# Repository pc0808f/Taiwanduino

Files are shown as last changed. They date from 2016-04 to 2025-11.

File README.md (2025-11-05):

# Taiwanduino

Hi, this is the official project site of Taiwanduino
* For our hardware design, please go to [/hardware][hw]
* Our software stuff (bootloader, driver, Arduino sketch...etc) is at [/software][sw]
* Our holder model has been released, it's located at [/holder][hd]

For installation or assembly instructions, see our [Wiki page][wiki]
Like our facebook [fan page][fb] for more info, online shop or donations!

[Changelog]
2025/11/05 (pc0808f fork) - v1.0.3
Fixed: Support for USBasp/USBtiny programmer with custom USB ID 1209:5457
Changed: Reverted to v1.0.2 style using arduino:usbtiny as upload tool
Programmer: "Taiwanduino" option available (uses local avrdude.conf for custom USB IDs)
Note: Direct upload uses Arduino core tools; "Upload Using Programmer" supports VID:1209 PID:5457

2025/10/29 (pc0808f fork) - v1.0.2
Fixed: Examples now visible in Arduino IDE after Board Manager installation
Added library.properties file for bundled library
Updated board package structure to follow Arduino specification

2025/10/28 (pc0808f fork) - v1.0.1
Updated board manager URL to pc0808f fork version
Re-committed zip file for GitHub Pages sync

2017/9/24
Add a 7 tones simple instrument example sketch

2016/11/11
Support for the latest CapacitiveSensor library from the Library Manager

2016/10/31
Holder v1.0 released

2016/10/27
Add pcm audio converter tools/pcm_converter
Cleanup example sketches

***

*Read this in other languages: [English](README.md), [繁體中文](README.zh-TW.md).*

TaiwanDuino

   [wiki]: <https://github.com/pc0808f/Taiwanduino/wiki>
   [hw]: <https://github.com/pc0808f/Taiwanduino/tree/master/hardware>
   [sw]: <https://github.com/pc0808f/Taiwanduino/tree/master/software>
   [hd]: <https://github.com/pc0808f/Taiwanduino/tree/master/holder>
   [fb]: <https://www.facebook.com/Taiwanduino>

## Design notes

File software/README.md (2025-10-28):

# Software

**Board Manager Installation** (Recommended)
   If you have the latest Arduino IDE, you can use *Board Manager* and *Library Manager* to download and install automatically

   Note: The board configuration files are located in `/hardware/Taiwanduino/avr/` directory

 - Board Configs
	 - [File] → [Preferences] → [Additional Board Manager URLs] and insert the URL below:
	   https://pc0808f.github.io/Taiwanduino/taiwanduino_pc0808f_index.json
	 - [Tools] → [Board: ""] → [Board Manager] and search for "Taiwanduino"
	 - Click the [Install] button

 - External libraries
	 - [Sketch] → [Include library] → [Manage Libraries] and search for "CapacitiveSensor"
	 - Click the [Install] button
	 - The library could be found in [PaulStoffregen/CapacitiveSensor](https://github.com/PaulStoffregen/CapacitiveSensor) if you want to import it manually

**Driver** contains drivers for Windows systems (it's a plug and play device for UNIX based systems like OS X or Linux)

**bootloader** contains the source code of the pre-programmed bootloader in TaiwanDuino

**example** is the folder of example sketches

**tools** includes EEPROM programmer and audio converters

***

*Read this in other languages: [English](README.md), [繁體中文](README.zh-TW.md).*

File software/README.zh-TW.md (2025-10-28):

# Software

**板子管理員安裝**（建議使用）
   可以透過下載最新版的 Arduino IDE 並使用內建的*板子管理員*及*管理程式庫*功能來自動安裝

   註：板子配置檔案位於 `/hardware/Taiwanduino/avr/` 目錄

 - 板子編譯資訊
	 - 請在 [檔案] → [偏好設定] → [額外的板子管理員網址]中輸入以下網址：
	   https://pc0808f.github.io/Taiwanduino/taiwanduino_pc0808f_index.json
	 - 進入 [工具] → [板子] → [板子管理員]中搜尋 Taiwanduino
	 - 按下 [安裝] 按鈕

 - 所使用的外部函式庫
	 - [草稿碼] → [匯入程式庫] → [管理程式庫]中搜尋 CapacitiveSensor
	 - 按下 [安裝] 按鈕
	 - 手動匯入外部程式庫請至 [PaulStoffregen/CapacitiveSensor](https://github.com/PaulStoffregen/CapacitiveSensor) 下載

**Driver** 資料夾中包含 Windows 作業系統所需驅動程式（OS X 和 Linux 為隨插即用）

**bootloader** 包含 TaiwanDuino 中所預燒的 bootloader 原始碼

**example** 為範例草稿碼的資料夾

**tools** 內有燒錄、製作音訊時所需的轉換工具

***

*其他語言版本: [English](README.md), [繁體中文](README.zh-TW.md).*

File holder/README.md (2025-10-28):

# Holder

We've finally finished the designing and testing process of our holder model, it contains screw pillars and a housing for your speaker.

 - Screw pillars are designed for any M2 screws (same size of the touchpad hole) within 7mm length.
 - The speaker housing includes 7 air holes and an internal support material to increase resonance, the bottom with air holes also acts like a mask to protect the diaphragm of speaker.

[holder_model-Main_Holder_STL.stl][stl] is the latest STL model you can print directly
[holder_model.blend][blend] is our project file made with Blender

***

*Read this in other languages: [English](README.md), [繁體中文](README.zh-TW.md).*

   [stl]: <holder_model-Main_Holder_STL.stl>
   [blend]: <holder_model.blend>

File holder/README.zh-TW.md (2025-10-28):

# 外殼

經過一連串的設計和測試，我們最終決定了包含螺絲腳柱和喇叭固定槽的外殼

 - 螺絲角柱的部分使用的是和觸控 PAD 相同孔徑的 M2 螺絲，小於 7mm 的 M2 螺絲都是可以被鎖上的
 - 喇叭固定槽包含 7 個發聲孔和一個 0.7mm 的增高墊，讓喇叭震模不會直接和外殼底面接觸，並且可以藉由發聲孔傳出聲波

進入 [holder_model-Main_Holder_STL.stl][stl] 下載可以直接進行列印的 STL 模型檔
進入 [holder_model.blend][blend] 下載本模型的 Blender 專案檔

***

*其他語言版本: [English](README.md), [繁體中文](README.zh-TW.md).*

   [stl]: <holder_model-Main_Holder_STL.stl>
   [blend]: <holder_model.blend>

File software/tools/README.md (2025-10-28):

# pcm_converter
Drag and drop multiple audio files and convert it to 8bit PCM audio

First, make a shortcut of this converter pcm_converter_en.bat and move it to where your audio file locate.
Drag and drop multiple audio/video file on the shortcut at once.
After the conversion, you will be able to find 8bit PCM(.wav) files in the /export folder.
Default sample rate and export location can be changed manually in the batch program.

Notice: An auto libav downloader will be triggered at the first time you start.

# wav2txt
Extracts converted the PCM(.WAV) audio file to an array of samples, paste it in sketch and play

Drag and drop the .wav file on writeWav.exe.
It will extract a text file(.txt) which has the same name as the original.
Paste the content (array+size variable) to your Arduino sketch and upload.

Notice: only 8khz/8bit or 16bit in a audio format of PCM will be available.

# wav2uart
Programs the converted the PCM(.WAV) audio file to external EEPROM, it must be connected through a Serial converter (i.e. FTDI)

First, upload the [example/uploadToFlash](../example/uploadToFlash) to your Taiwanduino.
Start wav2uart.exe
Copy and paste your file location in.
Choose the COM port device your Taiwanduino is connected.
Enter the data offset in EEPROM (where you start to program)

Notice: only 8khz/8bit or 16bit in a audio format of PCM will be available.

***

*Read this in other languages: [English](README.md), [繁體中文](README.zh-TW.md).*

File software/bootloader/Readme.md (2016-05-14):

# Arduino_Taiwan Bootloader

Modify from Adafruit ProTrinket
Change USB pin to 2/3
also change USB PID/VID

#using Avrdude to upload  

.\avrdude.exe  -c usbasp -p m328p -v -e  -U flash:w:main.hex -U lfuse:w:0xFF:m -U hfuse:w:0xD0:m -U efuse:w:0x06:m

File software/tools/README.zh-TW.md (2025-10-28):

# pcm_converter
把有帶音訊資料的任意影音檔案，透過拖曳的方式快速轉檔

直接將主程式 pcm_converter_tw.bat 檔建立一個捷徑並傳送到音效檔的資料夾
把所要轉換的一個或多個音效檔案拖曳到剛剛建立的捷徑上面即可完成轉檔
所輸出的檔案將會是 8 位元的 PCM 編碼 WAV 檔
預設取樣率和輸出資料夾可以至程式中進行手動更改

注意事項：第一次使用會先下載一份 libav 的轉檔器

# wav2txt
把 WAV 轉成程式碼，然後就可以貼上 example 播放

使用方式是把聲音檔案拖到 .exe 檔案裡面
之後會在同個地點多出一個 txt 檔案，把這檔案內容複製到
Arduino 的 Code 裡面就可以播放

注意事項：本程式只吃 8khz/8bit or 16bit 的 PCM 音效檔案

# wav2uart
把 WAV 轉檔案之後，直接輸出到 COM port 上傳到外部 EEPROM

首先要先把 [example/uploadToFlash](../example/uploadToFlash) 傳到板子
在來就是打開 exe 檔案
輸入檔案的路徑
選擇 COM port
輸入要從哪裡開始寫（初始位置的位移量）

注意事項：本程式只吃 8khz/8bit or 16bit 的 PCM 音效檔案

***

*其他語言版本: [English](README.md), [繁體中文](README.zh-TW.md).*

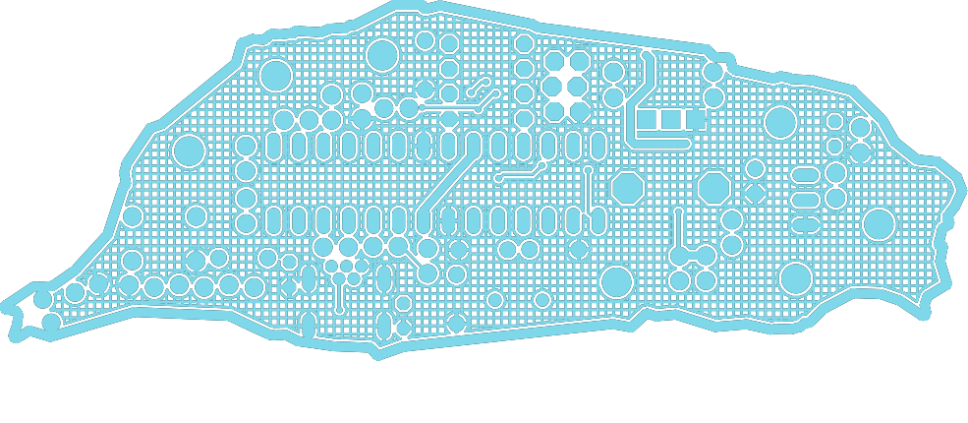
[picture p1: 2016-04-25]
hardware/pic/copper-bottom.png

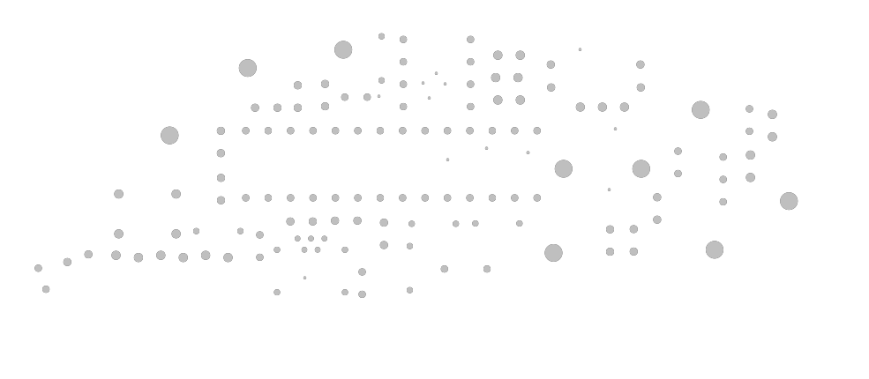
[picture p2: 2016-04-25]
hardware/pic/drill-01.png

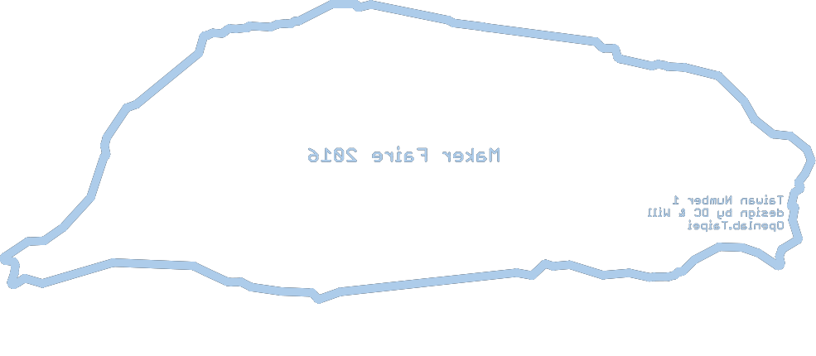
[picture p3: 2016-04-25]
hardware/pic/silkscreen-bottom.png

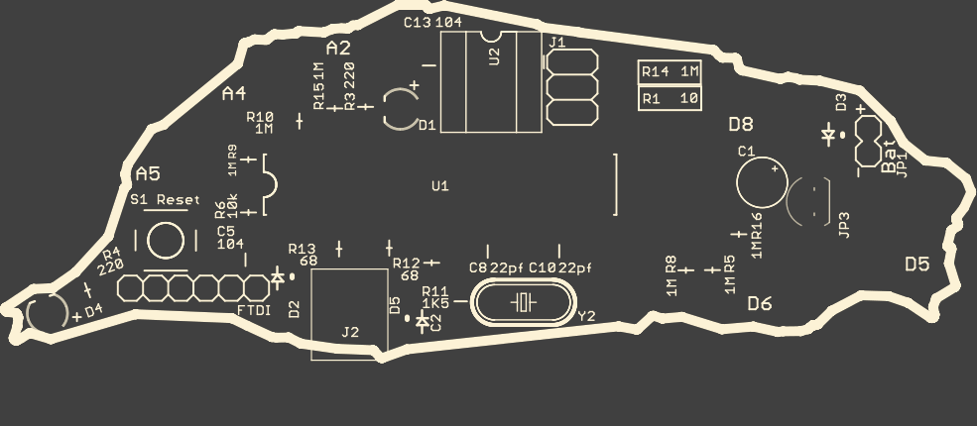
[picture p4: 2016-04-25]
hardware/pic/silkscreen-top.png

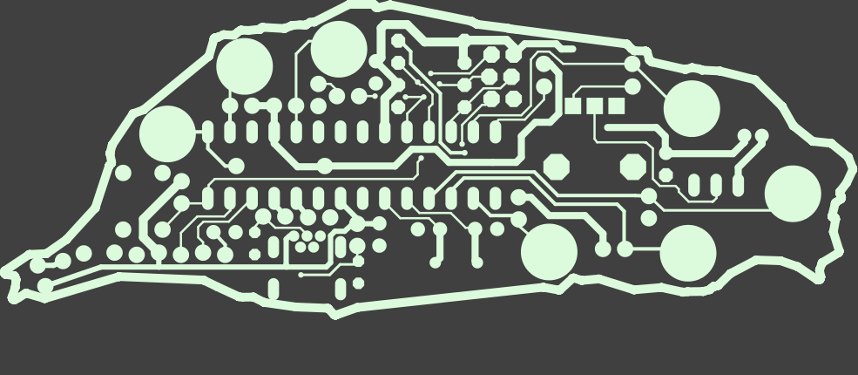
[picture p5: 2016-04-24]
hardware/pic/copper-top.png

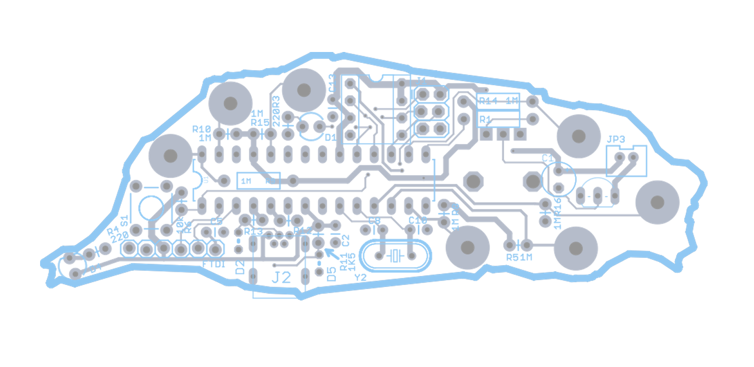
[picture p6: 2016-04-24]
PCB.PNG

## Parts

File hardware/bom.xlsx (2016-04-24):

Qty | Value | Device | Package | Parts | Description
1 |  | ARDUINO_SERIAL_PROGRAMLOCK | 1X06_LOCK | FTDI | FTDI connector footprints
2 |  | LED3MM | LED3MM | D1, D4 | LEDs
1 | 10 | RESISTOR | 1/4W | R1 | Resistor
1 |  | USB-MINIUSB-5P-TH | MINI-5P | J2
1 | 0.1uF | CAP | CAP-PTH-SMALL | C5 | Capacitor
2 | 0.1uf | CAP | CAP-PTH-SMALL | C2, C13 | Capacitor
1 | 100uf | CPOL-USE2.5-5 | E2,5-5 | C1 | POLARIZED CAPACITOR, American symbol
1 | 10k | RESISTOR | 1/4W | R6 | Resistor
1 | 16mhz | CRYSTAL | HC49U-V | Y2 | Various standard crystals. Proven footprints.
1 | 1K5 | RESISTOR | 1/4W | R11 | Resistor
7 | 1M | RESISTOR | 1/4W | R5, R8, R10, R15, R16,R9, R14 | Resistor
2 | 220 | 1/4W | 1/4W | R3, R4 | Resistor
2 | 22pf | CAP | CAP-PTH-SMALL | C8, C10 | Capacitor
1 | 2N | 2N2222 | TO92-EBC-OVAL | T2 | NPN TRANSISTOR
2 | 3.3V | DIODE-VERTDIODE_SM_VERT | 0204V | D2, D5 | DIODE
1 | 5k | POT | ALPS_POT | RV1
2 | 68 | RESISTOR | 1/4W | R12, R13 | Resistor
1 | ATMEGA328P | ATMEGA328P | DIL28-3 | U1 | uC used in the Arduino
1 | M02X03 | AVR_ISP | 2X3_LOCK | J1 | AVR ISP 6 Pin
1 | M02 | M02JST-PTH-VERT | JST-2-PTH-VERT | JP3 | Standard 2-pin 0.1 header. Use with"
1 | SPI_FLASH-X25XX | SPI_FLASH-X25XX | DIL08 | U$1 | 8pin SPI Flash series x25xx. Works with devices like W25X32 and BR25L32
1 | SWITCH-MOMENTARY-2PTH | SWITCH-MOMENTARY-2PTH | TACTILE-PTH | S1 | Various NO switches- pushbuttons, reed, etc

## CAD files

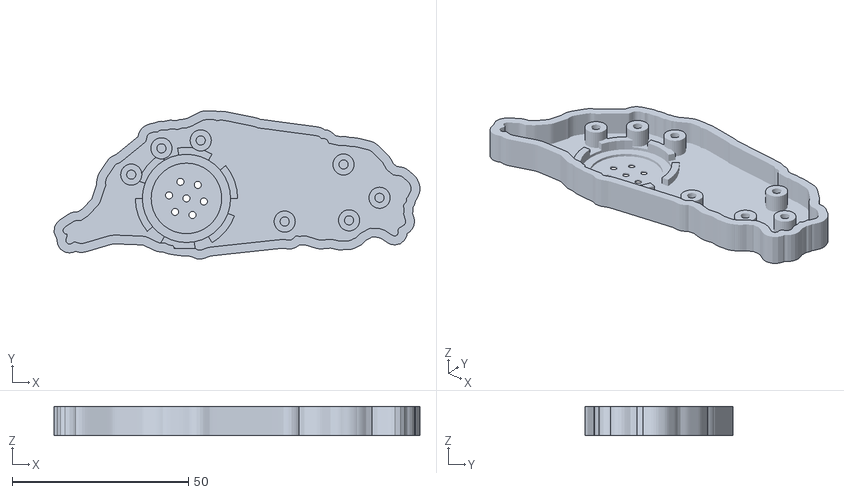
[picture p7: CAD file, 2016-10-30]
holder/holder_model-Main_Holder_STL.stl
103.7 x 42.0 x 8.30

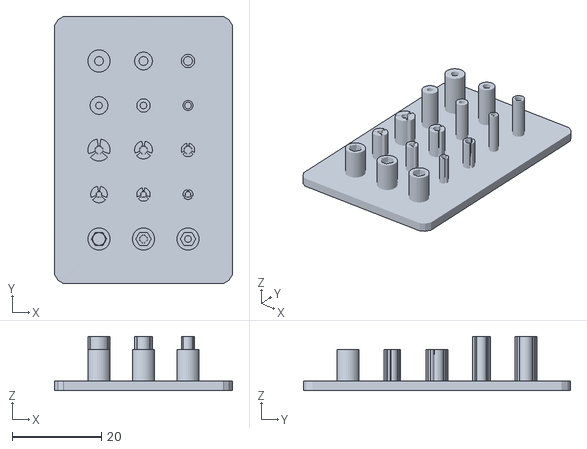
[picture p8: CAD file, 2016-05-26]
holder/ScrewTester/ScrewTest-ScrewTestbench.stl
40.0 x 60.0 x 12.2

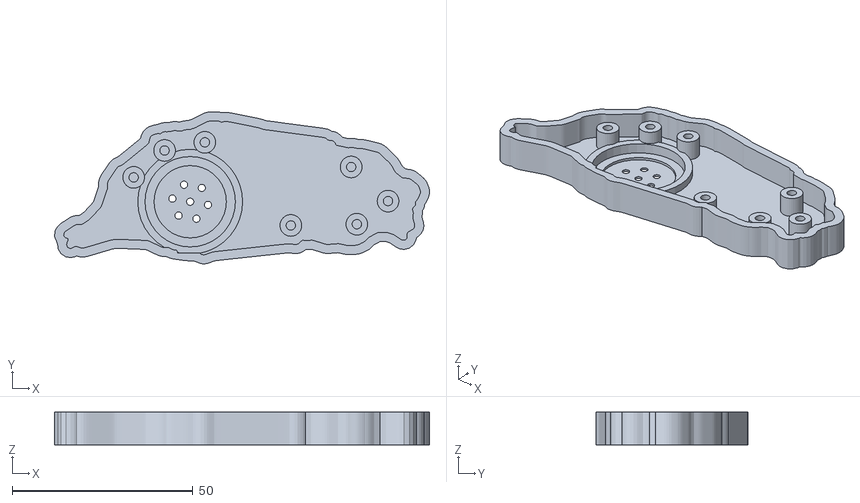
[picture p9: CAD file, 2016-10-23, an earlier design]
holder/Main_Holder_old/Main_Holder_1023.stl
103.7 x 42.0 x 9.00

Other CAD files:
holder/Main_Holder_old/Main_Holder_1024.stl
holder/Main_Holder_old/case-Main_Holder_0526.stl
holder/ScrewTester/ScrewTest.blend

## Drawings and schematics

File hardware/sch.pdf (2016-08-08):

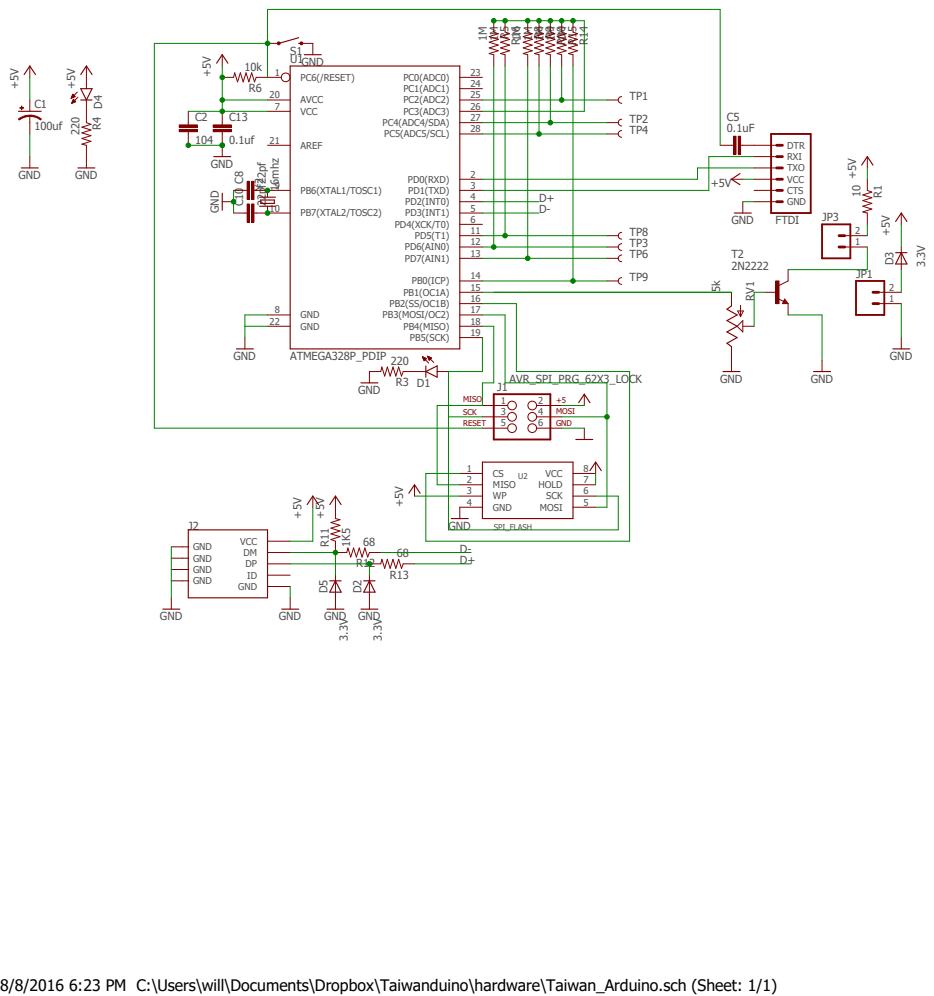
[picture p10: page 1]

SCK | | MOSI
RESET | | GND

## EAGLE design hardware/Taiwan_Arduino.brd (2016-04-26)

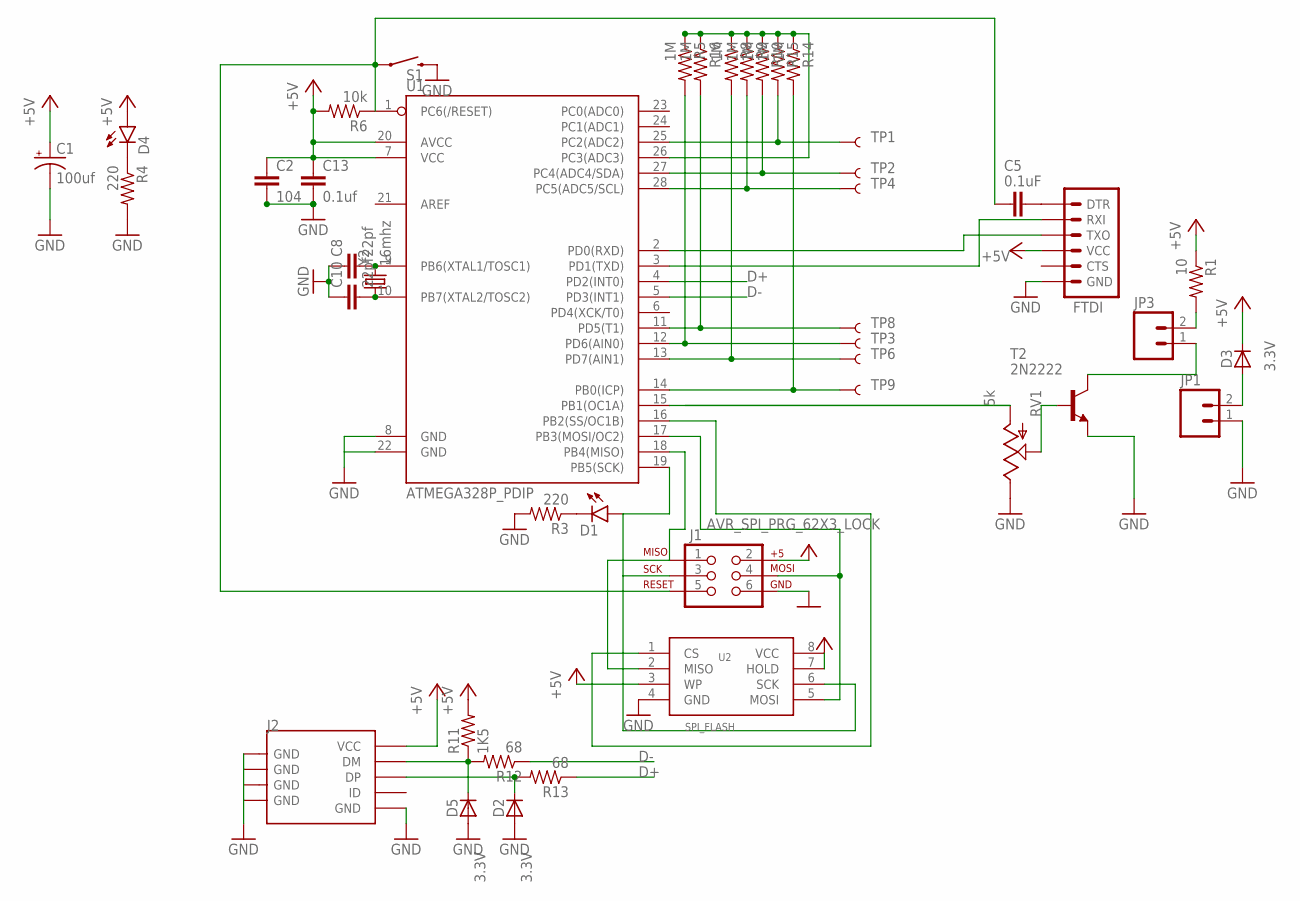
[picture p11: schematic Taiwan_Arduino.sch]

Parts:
C1: 100uf; E2,5-5
C2: 104; CAP-PTH-5MM
C5: 0.1uF; CAP-PTH-5MM
C8, C10: 22pf; CAP-PTH-5MM
C13: 0.1uf; CAP-PTH-5MM
D1, D4: LED3MM
D2, D3, D5: 3.3V; 0204V
FTDI: ARDUINO_SERIAL_PROGRAMLOCK; 1X06_LOCK
J1: AVR_SPI_PRG_62X3_LOCK; 2X3_LOCK
J2: USB-MINIUSB-5P-TH; MINI-5P
JP1: Battery; 1X02
JP3: M021X02_NO_SILK; 1X02_NO_SILK
R1: 10; AXIAL-0.1
R3, R4: 220; AXIAL-0.1
R5, R8, R9, R10, R15, R16: 1M; AXIAL-0.1
R6: 10k; AXIAL-0.1
R11: 1K5; AXIAL-0.1
R12, R13: 68; AXIAL-0.1
R14: 1M; AXIAL-0.4
RV1: 5k; ALPS_POT
S1: SWITCH-MOMENTARY-2PTH; TACTILE-PTH
T2: 2N2222; TO92-EBC-OVAL
TP1, TP2, TP3, TP4, TP6, TP8, TP9: TEST-POINT; PADBIG
U1: ATMEGA328P_PDIP; DIL28-3
U2: SPI_FLASH; DIL08
Y2: 16mhz; HC49U-V

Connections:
1: R8.P$2 (2), TP6.P$1, U1.13 (PD7(AIN1))
+5V: C1.+, C2.1, C13.1, D3.2 (C), D4.A, FTDI.4 (VCC), J1.2, J2.VCC, R1.P$1 (1), R6.P$2 (2), R11.P$2 (2), U1.7 (VCC), U1.20 (AVCC), U2.3 (WP), U2.7 (HOLD), U2.8 (VCC)
D+: R13.P$1 (1), U1.4 (PD2(INT0))
D-: R12.P$1 (1), U1.5 (PD3(INT1))
GND: C1.-, C2.2, C8.1, C10.1, C13.2, D2.1 (A), D5.1 (A), FTDI.6 (GND), J1.6, J2.GND, J2.S1 (GND), J2.S2 (GND), J2.S3 (GND), J2.S4 (GND), JP1.1, R3.P$2 (2), R4.P$2 (2), RV1.P$1 (E), S1.3 (2), T2.E, U1.8 (GND), U1.22 (GND), U2.4 (GND)
unnamed: JP3.2, R1.P$2 (2)
unnamed: RV1.P$3 (A), U1.15 (PB1(OC1A))
unnamed: R14.P$2 (2), TP9.P$1, U1.14 (PB0(ICP))
unnamed: C8.2, U1.9 (PB6(XTAL1/TOSC1)), Y2.2
unnamed: R15.P$2 (2), TP1.P$1, U1.25 (PC2(ADC2))
unnamed: D1.A, J1.3, U1.19 (PB5(SCK)), U2.6 (SCK)
unnamed: R10.P$2 (2), TP2.P$1, U1.27 (PC4(ADC4/SDA))
unnamed: R9.P$2 (2), TP4.P$1, U1.28 (PC5(ADC5/SCL))
unnamed: FTDI.3 (TXO), U1.2 (PD0(RXD))
unnamed: J1.1, U1.18 (PB4(MISO)), U2.2 (MISO)
unnamed: R5.P$1 (1), R8.P$1 (1), R9.P$1 (1), R10.P$1 (1), R14.P$1 (1), R15.P$1 (1), R16.P$1 (1), U1.26 (PC3(ADC3))
unnamed: JP3.1, T2.C
unnamed: C10.2, U1.10 (PB7(XTAL2/TOSC2)), Y2.1
unnamed: FTDI.2 (RXI), U1.3 (PD1(TXD))
unnamed: D5.2 (C), J2.DM, R11.P$1 (1), R12.P$2 (2)
unnamed: D2.2 (C), J2.DP, R13.P$2 (2)
unnamed: R16.P$2 (2), TP8.P$1, U1.11 (PD5(T1))
unnamed: D3.1 (A), JP1.2
unnamed: D1.K (C), R3.P$1 (1)
unnamed: RV1.P$2 (S), T2.B
unnamed: J1.4, U1.17 (PB3(MOSI/OC2)), U2.5 (MOSI)
unnamed: D4.K (C), R4.P$1 (1)
unnamed: C5.2, FTDI.1 (DTR)
unnamed: U1.16 (PB2(SS/OC1B)), U2.1 (CS)
unnamed: R5.P$2 (2), TP3.P$1, U1.12 (PD6(AIN0))
RST: C5.1, J1.5, R6.P$1 (1), S1.1, U1.1 (PC6(/RESET))

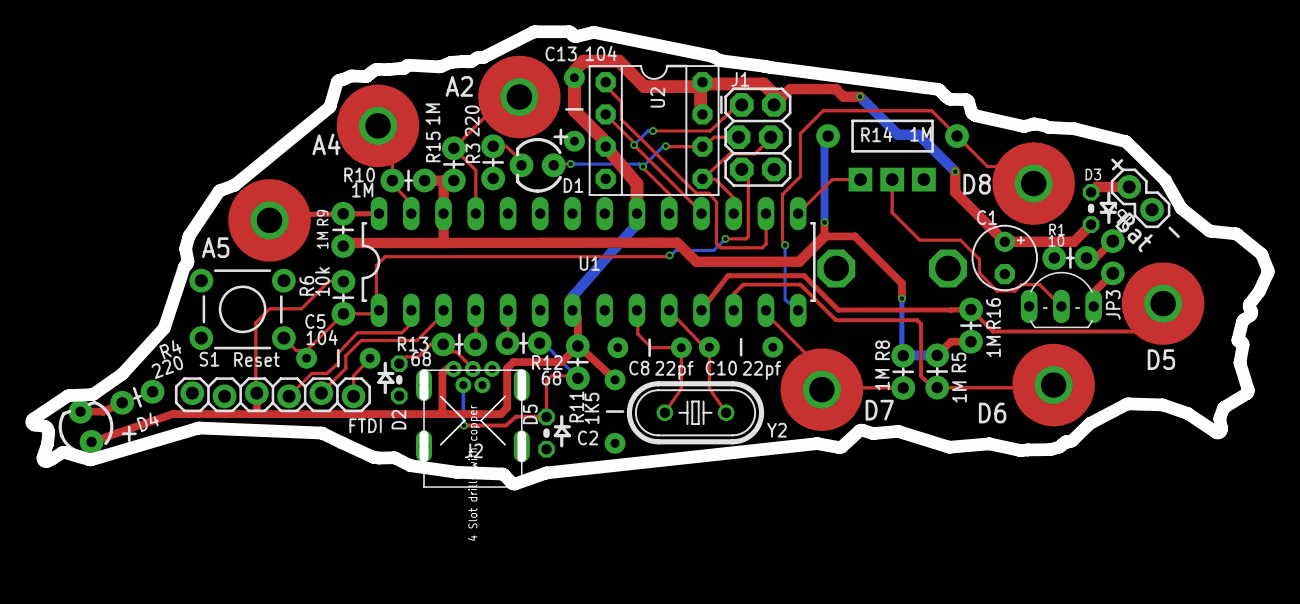
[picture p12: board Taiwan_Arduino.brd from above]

Board: 2 copper layers, 97.4 x 35.6 mm, 43 parts (0 on the bottom side), 31 nets.

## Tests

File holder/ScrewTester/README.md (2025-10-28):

# ScrewTester

This is an experimental tool used to test screw pillar printing, we used it to find the most suitable screw pillar design.

***

*Read this in other languages: [English](README.md), [繁體中文](README.zh-TW.md).*

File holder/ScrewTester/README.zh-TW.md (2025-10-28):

# ScrewTester

這是一個用來測試螺絲柱印製的實驗工具，我們用它來找出最合適的螺絲柱設計

***

*其他語言版本: [English](README.md), [繁體中文](README.zh-TW.md).*

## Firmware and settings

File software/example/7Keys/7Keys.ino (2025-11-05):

#include <CapacitiveSensor.h>

#define Threadhold 200		//scan button threadhold

int input_pin[7] = {A5,A4,A2,8,5,6,7};	//define touchpad pinouts
CapacitiveSensor *input[7];				//create an CapacitiveSensor object for use in this sketch


//1 period sine of 500Hz
const uint8_t sound1_data[] PROGMEM = {0 ,10 ,37 ,79 ,128 ,177 ,219 ,246 ,255 ,246 ,219 ,177 ,128 ,79 ,37 ,10 ,};
const int sound1_length=16;

int scanbutton(){
	int total[7] = {0};
	for(byte i=0;i<7;i++){
		total[i] =  input[i]->capacitiveSensor(30);
		if(total[i] >= Threadhold){
			/*uncomment while debugging*/
			//Serial.print(F("Button "));
			//Serial.println(i);
			return i;
		}
	}
	return -1;
}

void play(const uint8_t sound_data[], int sound_length, uint32_t samplesdelay, uint32_t stoptime){
	uint32_t counter=0;
	uint32_t last=0;
	stoptime+=millis();
	byte decay = 0;
	while(millis() < stoptime){
		if((stoptime - millis()<1))decay++;
		if(micros()-last > samplesdelay){
			OCR1A = (pgm_read_byte_near(sound_data+counter) >> (byte)(decay*0.1));
			counter++;
			last = micros();
		}
		if(counter == sound_length)counter = 0;
	}
}

void setup(){	
	//Initialize Serial
	Serial.begin(9600);
	Serial.println(F("Started"));
	
	//Initialize I/O
	pinMode(A3, OUTPUT);		//capacitive sensor switcher
	pinMode(9, OUTPUT);			//speaker output
	pinMode(13, OUTPUT);		//LED Chiayi
	
	//Initialize Capacitive Sensor
	Serial.print(F("Initializing Capacitive Sensor..."));
	for(int i=0;i<7;i++)input[i] = new CapacitiveSensor(A3,input_pin[i]);
	Serial.println(F("done."));

	TCCR1B = (1 << WGM12) | (0 << WGM13)| (1 << CS10);
	TCCR1A = (1 << COM1A1)|(1 << WGM10) | (0 << WGM11);

}
//frequency of tone C D E F G A B
float tone_f[7] = {261.63, 293.66, 329.63, 349.23, 392.00, 440.00, 493.88};
byte keypressed = 0;
byte octave = 0;
 
void loop(){
	short int key = scanbutton();
	if(key != -1){
		keypressed = keypressed | (1 << key);
		digitalWrite(13,HIGH);
		//125ms delay generates sine wave in 500Hz
		//(125*500)ms generates 1Hz 
		//(125*500)ms/(tone_f[n]) generates tone_f[n] (hz)
		play(sound1_data, sound1_length, (uint32_t)((float)(125.0*500.0/tone_f[6-key])) << octave, 200);
		digitalWrite(13,LOW);
	}
	if(keypressed == 0b01111111){
		//after all key was touched
		octave++;
		keypressed = 0;
	}
}

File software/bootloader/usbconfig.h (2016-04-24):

/* Name: usbconfig.h
 * Project: V-USB, virtual USB port for Atmel's(r) AVR(r) microcontrollers
 * Author: Christian Starkjohann
 * Creation Date: 2005-04-01
 * Tabsize: 4
 * Copyright: (c) 2005 by OBJECTIVE DEVELOPMENT Software GmbH
 * License: GNU GPL v2 (see License.txt), GNU GPL v3 or proprietary (CommercialLicense.txt)
 * This Revision: $Id$
 */
 
/* Modified by me@frank-zhao.com for project VUSBtinyBoot
 *  
 * VUSBtinyBoot is a bootloader that emulates a USBtinyISP (from Adafruit Industries)
 *  
 * Trinket Pro will use VUSBtinyBoot
 *
 * This code is heavily derived from USBaspLoader, but also from USBtiny, with USBtinyISP's settings
 */

#ifndef __usbconfig_h_included__
#define __usbconfig_h_included__

/* YOU SHOULD NOT NEED TO MODIFY THIS FILE! All configurations are supposed
 * to go into bootloaderconfig.h!
 */

/* ---------------------------- Hardware Config ---------------------------- */

/* All the port and pin assignments, as well as the clock speed and CRC
   setting are now in bootloaderconfig.h: */

#include "bootloaderconfig.h"

/* --------------------------- Functional Range ---------------------------- */

#define USB_CFG_HAVE_INTRIN_ENDPOINT    0
/* Define this to 1 if you want to compile a version with two endpoints: The
 * default control endpoint 0 and an interrupt-in endpoint (any other endpoint
 * number).
 */
#define USB_CFG_HAVE_INTRIN_ENDPOINT3   0
/* Define this to 1 if you want to compile a version with three endpoints: The
 * default control endpoint 0, an interrupt-in endpoint 3 (or the number
 * configured below) and a catch-all default interrupt-in endpoint as above.
 * You must also define USB_CFG_HAVE_INTRIN_ENDPOINT to 1 for this feature.
 */
#define USB_CFG_EP3_NUMBER              3
/* If the so-called endpoint 3 is used, it can now be configured to any other
 * endpoint number (except 0) with this macro. Default if undefined is 3.
 */
/* #define USB_INITIAL_DATATOKEN           USBPID_DATA1 */
/* The above macro defines the startup condition for data toggling on the
 * interrupt/bulk endpoints 1 and 3. Defaults to USBPID_DATA1.
 * Since the token is toggled BEFORE sending any data, the first packet is
 * sent with the oposite value of this configuration!
 */
#define USB_CFG_IMPLEMENT_HALT          0
/* Define this to 1 if you also want to implement the ENDPOINT_HALT feature
 * for endpoint 1 (interrupt endpoint). Although you may not need this feature,
 * it is required by the standard. We have made it a config option because it
 * bloats the code considerably.
 */
#define USB_CFG_SUPPRESS_INTR_CODE      0
/* Define this to 1 if you want to declare interrupt-in endpoints, but don't
 * want to send any data over them. If this macro is defined to 1, functions
 * usbSetInterrupt() and usbSetInterrupt3() are omitted. This is useful if
 * you need the interrupt-in endpoints in order to comply to an interface
 * (e.g. HID), but never want to send any data. This option saves a couple
 * of bytes in flash memory and the transmit buffers in RAM.
 */
#define USB_CFG_INTR_POLL_INTERVAL      10
/* If you compile a version with endpoint 1 (interrupt-in), this is the poll
 * interval. The value is in milliseconds and must not be less than 10 ms for
 * low speed devices.
 */
#ifndef USB_CFG_IS_SELF_POWERED // allow bootloaderconfig.h to override
#define USB_CFG_IS_SELF_POWERED         0
#endif
/* Define this to 1 if the device has its own power supply. Set it to 0 if the
 * device is powered from the USB bus.
 */
#ifndef USB_CFG_MAX_BUS_POWER   // allow bootloaderconfig.h to override
#define USB_CFG_MAX_BUS_POWER           100
#endif
/* Set this variable to the maximum USB bus power consumption of your device.
 * The value is in milliamperes. [It will be divided by two since USB
 * communicates power requirements in units of 2 mA.]
 */
#define USB_CFG_IMPLEMENT_FN_WRITE      1
/* Set this to 1 if you want usbFunctionWrite() to be called for control-out
 * transfers. Set it to 0 if you don't need it and want to save a couple of
 * bytes.
 */
#define USB_CFG_IMPLEMENT_FN_READ       1
/* Set this to 1 if you need to send control replies which are generated
 * "on the fly" when usbFunctionRead() is called. If you only want to send
 * data from a static buffer, set it to 0 and return the data from
 * usbFunctionSetup(). This saves a couple of bytes.
 */
#define USB_CFG_IMPLEMENT_FN_WRITEOUT   0
/* Define this to 1 if you want to use interrupt-out (or bulk out) endpoints.
 * You must implement the function usbFunctionWriteOut() which receives all
 * interrupt/bulk data sent to any endpoint other than 0. The endpoint number
 * can be found in 'usbRxToken'.
 */
#define USB_CFG_HAVE_FLOWCONTROL        0
/* Define this to 1 if you want flowcontrol over USB data. See the definition
 * of the macros usbDisableAllRequests() and usbEnableAllRequests() in
 * usbdrv.h.
 */
#define USB_CFG_DRIVER_FLASH_PAGE       0
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

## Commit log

2016-03-18 Replaace bypass cap
    [Taiwan_Arduino.brd, Taiwan_Arduino.sch]
2016-03-19 Layout fixed
    1.reduce via under the 328p mcu
    2.fix the reset pin routing of the isp header
    3.beef up the power/ground wires near C13 / reset button and USB shell
    4.rotate the speaker header and transistors 45 deg
    5.make more space for capacitor C1/C2
    [Taiwan_Arduino.brd, Taiwan_Arduino.sch]
2016-03-19 Added files via upload
    1.change usb D+D- lines to top layer
    2.reroute the VCC line between C13 and EEPROM to prevent TP1 isolated from ground plane
    3.fix the SCK line from ISP header to EEPROM
    [Taiwan_Arduino.brd]
2016-03-21 Improve touch pad grounding
    [Taiwan_Arduino.brd, Taiwan_Arduino.sch]
2016-03-21 improve Cap sense
    [Taiwan_Arduino.brd]
2016-03-26 Ver 1.0
    [Taiwan_Arduino.GBL, Taiwan_Arduino.GBO, Taiwan_Arduino.GBP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]
2016-03-29 Ver 0.9
    [Taiwan_Arduino.GBL, Taiwan_Arduino.GBO, Taiwan_Arduino.GBP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]
2016-04-11 28mm/26mm round speaker compatible
    logo text not joined in stl
    0.5mm speaker protection film
    [case-TW_CircleSPKR_Through26_4.stl, case-TW_CircleSPKR_Through28_4.stl]
2016-04-24 add Driver and Arduino Plugin
2016-04-25 add tag on IO
    [Taiwan_Arduino.brd]
2016-04-25 add tag on FTDI port
    [Taiwan_Arduino.brd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]
2016-04-25 add FTDI pin labels
    [Taiwan_Arduino.brd, Taiwan_Arduino.sch]
2016-04-25 add FTDI Tag
    [Taiwan_Arduino.brd, Taiwan_Arduino.sch]
2016-04-26 Fix 10 ohm R1
    [Taiwan_Arduino.brd, Taiwan_Arduino.sch]
2016-05-26 Added screw holes and battery holder
    [ScrewTest-ScrewTestbench.stl, ScrewTest.blend, case-Main_Holder_0526.stl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]
2016-06-03 Fix Arduino plugin
2016-06-06 Change board name and avrdude.conf position
2016-08-12 add boardmanager support
2016-10-23 fixed multiple issue
    1. sketch function compilling problem
    2. rename case to holder, prepare for release
    3. cleanup EEPROM_Playback sketch
    [Main_Holder_1023.stl, ScrewTest-ScrewTestbench.stl, ScrewTest.blend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]
2016-10-30 holder v1.0 released
    [Main_Holder_1024.stl, holder_model-Main_Holder_STL.stl]
2016-11-11 fix library issue
    switch to original CapacitiveSensor library instead of the costomized
    one
2016-11-11 remove customized library
    1. remove customized CapacitiveSensor library
    2. update READMEs
2017-06-06 fix inconsistent file types
    fix inconsistent file types unsigned char into uni8_t to match the test
    samples in comment
2025-10-28 Update URLs, changelog, and convert documentation to English-first bilingual format
    - Update board manager URLs from will127534 to pc0808f fork version
    - Add changelog entries for pc0808f fork modifications
    - Convert all README files to English-first with Chinese translations
    - Maintain bilingual support for better accessibility
2025-10-28 Refactor: Split bilingual READMEs into separate English and Chinese files
    - Rename README.en.md to README.md (English as default)
    - Create README.zh-TW.md for Traditional Chinese versions
    - Apply changes to all README files across the project
    - Update language switcher links to new naming convention
    - Remove old README.en.md files to avoid confusion
    This improves readability by keeping each language in separate files
    instead of mixing both languages in one file.
2025-10-28 Add example sketches to board package
    - Add libraries/Taiwanduino/examples/ directory structure
    - Include all 4 example sketches: 7Keys, EEPROM_Playback, Taiwan_NO1, uploadToFlash
    - Update Taiwanduino-1.0.1.zip package (size: 123674 bytes)
    - Update taiwanduino_pc0808f_index.json with new checksum and size
    - Examples will now appear in Arduino IDE after installing the board package
    This fixes the issue where examples were missing from the board manager installation.
2025-10-28 Remove outdated Arduino plugin directory and temp files
    - Remove software/Arduino plugin/hardware/Taiwanduino/avr/ (version 1.0.0)
    - Remove taiwanduino-1.0.1/ temporary directory
    - Keep only hardware/Taiwanduino/avr/ (version 1.0.1) as the authoritative source
    - This eliminates confusion between duplicate board configurations
    The hardware directory contains:
    - Latest platform.txt (v1.0.1) with runtime.tools configuration
    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
2025-10-28 Update software README to reflect correct directory structure
    - Remove reference to removed "Arduino plugin" directory
    - Update documentation to point to /hardware/Taiwanduino/avr/
    - Clarify that board manager installation is the recommended method
    - Apply changes to both English and Chinese versions
2025-10-29 Release version 1.0.2 with library.properties for examples
    Major Fix:
    - Add library.properties file to make examples visible in Arduino IDE
    - This file is required by Arduino IDE to recognize the library and show examples
    Changes:
    - Add hardware/Taiwanduino/avr/libraries/Taiwanduino/library.properties
    - Update version to 1.0.2 in platform.txt and library.properties
    - Create Taiwanduino-1.0.2.zip package (size: 124,147 bytes)
    - Update taiwanduino_pc0808f_index.json with new version
    Without library.properties, Arduino IDE does not recognize the bundled library,
    and therefore examples won't appear in File → Examples menu. This fix ensures
    users can access all 4 example sketches after instal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
2025-11-05 Add version 1.0.3 to board manager index
    - Added v1.0.3 platform entry with updated checksum
    - Included Taiwanduino-1.0.3.zip archive
    - Retained v1.0.2 for backward compatibility
2025-11-05 Fix v1.0.3 ZIP file structure for Arduino Board Manager
    - Corrected ZIP archive to have files at root level (not nested in subdirectories)
    - Updated checksum: 559d7c2dd31c77585e55c7a6713c53aba3e25415099f8669913a22bba7e22749
    - Updated size: 124021 bytes
    This fixes the installation issue where v1.0.3 appeared to install but failed to work properly.
2025-11-05 Fix v1.0.3 ZIP archive structure with proper root directory
    - Added 'taiwanduino-1.0.3' as root directory in ZIP (required by Arduino IDE)
    - Updated checksum: 43abfaeb9ebbd9ba3bbbcb0b4129063587d9cdc9d71538b9acab11f535819960
    - Updated size: 124513 bytes
    This resolves the "no unique root dir in archive" error during installation.
2025-11-05 Improve v1.0.3 with custom programmer definitions and USB ID support
    - Added distinct programmer definitions in programmers.txt:
    * Taiwanduino-USBasp (VID:1209 PID:5457) for custom USB IDs
    * Taiwanduino-USBtiny for standard USBtiny protocol
    * Standard USBtinyISP and USBasp options retained
    - Modified boards.txt to use avrdude with usbasp protocol
    - Fixed platform.txt upload pattern to include {upload.extra_params}
    - Updated README files with detailed changelog
    This addresses:
    - Programmer selection confusion in Arduino IDE
    - Custom USB VID:PID (1209:5457) support
    - Proper parameter passing to avrdude
    Co-Autho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
2025-11-05 Fix v1.0.3: Revert to v1.0.2-style programmer configuration
    - Simplified programmers.txt following v1.0.2 pattern:
    * usbtinyisp -> "Taiwanduino-USBasp" using protocol "Taiwanduino"
    * usbasp -> "Taiwanduino-USBtiny" using protocol "usbtiny"
    * Removed (VID:1209 PID:5457) from display name
    - Updated boards.txt to use protocol "Taiwanduino" (defined in avrdude.conf)
    - Removed upload.extra_params (handled by avrdude.conf programmer definition)
    - Updated checksum: 8c5b664ad0746c682e7dc891fa1e9a24c7e26a12041efb8fb1a7bae2bcfae1cd
    The "Taiwanduino" programmer in avrdude.conf specifies VID:1209 PID:5457.
    Co-Authored-By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
2025-11-05 Fix v1.0.3: Correct programmer associations and upload pattern
    - Fixed programmer associations in programmers.txt:
    * usbtinyisp -> "Taiwanduino-USBtiny" (standard usbtiny protocol)
    * usbasp -> "Taiwanduino-USBasp" (Taiwanduino protocol with VID:1209 PID:5457)
    - Added {upload.verbose} to upload.pattern for proper parameter passing
    - Added upload.maximum_data_size to boards.txt
    - Updated checksum: 193acd083b7ed85703c507e487900b83112fba854309bb6ea25286c5216fac71
    This fixes:
    1. Reversed programmer name associations
    2. Upload not executing (only reading device signature)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
2025-11-05 Release v1.0.3: Revert to v1.0.2-style configuration with custom USB ID support
    - Reverted boards.txt to use arduino:usbtiny (Arduino core tool)
    - Simplified programmers.txt with single "Taiwanduino" option
    - Removed upload.protocol from boards (handled by Arduino core)
    - FTDI configuration unchanged and verified
    Configuration:
    - Direct upload: Uses Arduino core tools (standard USB IDs)
    - Upload Using Programmer: Uses local avrdude.conf (supports VID:1209 PID:5457)
    - Programmer menu: "Taiwanduino" option available
    This provides compatibility with v1.0.2 while maintaining custom USB ID support
    through the "Upload Using Programmer" workflow.
    Updated checksum: d415d447e41b8cced18b2b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
2025-11-05 Fix 7Keys audio playback: Use floating-point arithmetic for frequency calculation
    將頻率計算從整數運算 (125*500) 改為浮點數運算 (125.0*500.0)，
    修正因整數除法截斷導致的音調計算錯誤，確保按鍵音效正確播放。
    [7Keys.ino]
2025-11-05 Add USB driver support for automatic installation
    整合 libusbK USB 驅動程式到 hardware/Taiwanduino/avr/drivers 目錄，
    Arduino IDE 在安裝板子定義時會自動檢測並提示安裝驅動程式。
    驅動程式內容：
    - USBtiny.inf/cat: 驅動程式安裝資訊與簽章
    - 支援 x86, AMD64, ARM64 架構
    - 包含 libusbK 和 libusb0 驅動程式檔案
    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
2025-11-05 Remove outdated USB driver from software/Driver
    移除舊版 libusb-win32 驅動程式（v1.2.4.0, 2011年），
    已被新版 libusbK 驅動程式取代（v3.1.0.0, 2024年）。
    新版驅動程式位於 hardware/Taiwanduino/avr/drivers/，
    提供更好的支援：
    - 更新的驅動程式版本
    - 支援 ARM64 架構（舊版僅支援 x86/amd64/ia64）
    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
2025-11-05 update to 1.0.4 with driver

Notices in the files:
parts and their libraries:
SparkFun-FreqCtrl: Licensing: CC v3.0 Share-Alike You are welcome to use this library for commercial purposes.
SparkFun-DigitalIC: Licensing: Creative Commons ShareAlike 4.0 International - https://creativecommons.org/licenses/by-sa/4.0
